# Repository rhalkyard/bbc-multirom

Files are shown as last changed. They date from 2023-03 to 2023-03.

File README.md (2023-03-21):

# MultiROM: A low-cost BBC Master / Electron ROM cartridge

There are plenty of perfectly-good options for building ROM cartridges for the BBC Master and Acorn Electron Plus One. However, I am a stubborn git and enjoy reinventing the wheel for fun, so I decided to come up with my own take on the concept.

Rather than use the 27x and 28x series (E)EPROMS that were used Back In The Day, MultiROM uses a NOR Flash IC, the SST39SF010A. This part is much cheaper and more readily available than EEPROMs, but can still be obtained as a through-hole part for easy DIY assembly. Additionally, it offers more capacity (a whopping one megabit!), which MultiROM uses to store multiple ROM images on one cartridge, selected by DIP switches.

The schematic and PCB layout were produced using [KiCad 7.0](https://www.kicad.org/).

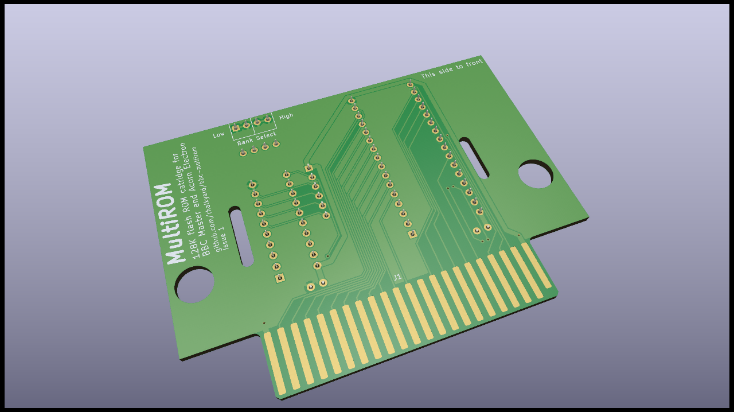
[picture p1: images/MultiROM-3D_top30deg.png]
Three-quarter view of front side of PCB

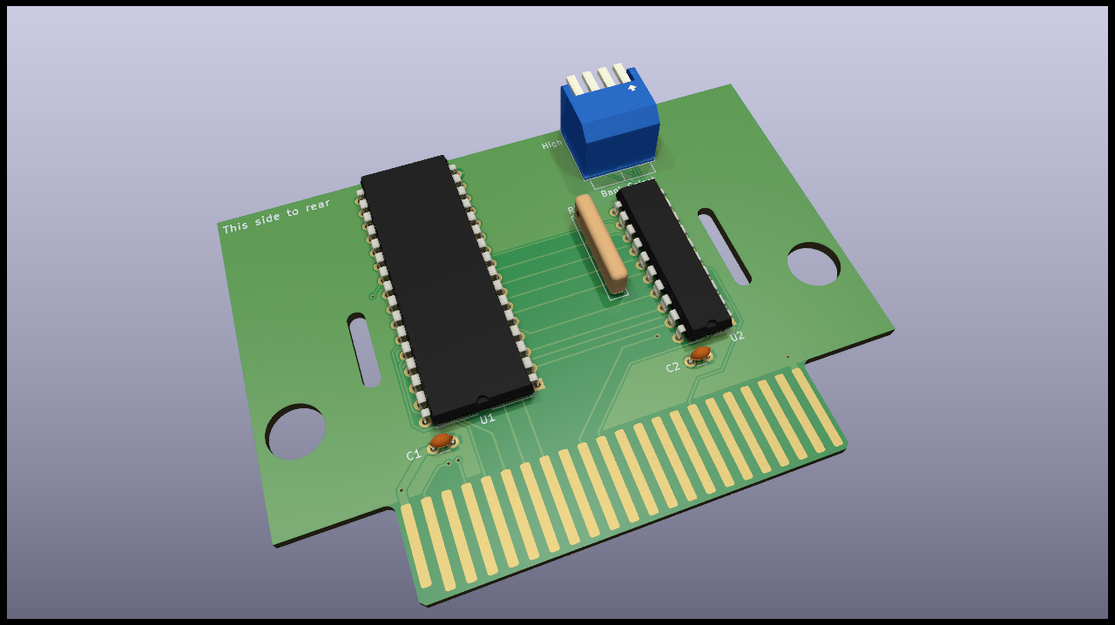
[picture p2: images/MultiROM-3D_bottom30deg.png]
Three-quarter view of rear side of PCB


## How to build MultiROM

### Bill of Materials

Reference   | Part
------------|-------------------------------------------------------------
`C1`, `C2`  | Ceramic capacitor, 0.1μF
`RN1`       | SIP6 resistor network, bussed, 10KΩ
`SW1`       | SPST DIP switch module, 4 switches
`U1`        | SST39SF010 1Mbit flash memory, DIP32 package
`U2`        | GAL16V8 or ATF16V8 programmable logic device, DIP20 package

`RN1` can be omitted if you trust the weak pull-ups built into `U2`. I forgot to order it when building my prototypes, and they seem to work just fine without it.

`SW1` can be omitted if you want the cartridge to function as a basic 2x16k catridge without bank switching.

### PCB

Any PCB fabricator service such as PCBWay, OSHPark or JLCPCB should be able to fabricate the board. Some shops will accept the `.kicad_pcb` file directly, but most will require Gerber and drill files. These can be exported from Kicad using the File -> Fabrication Outputs menu options.

Ideally, the edge connector should have a chamfered board edge and hard gold-plated contacts, to avoid damaging the PCB socket and to ensure a good connection. These are usually extra-cost options that have to be requested when placing the order.

When assembling components onto the PCB, pay attention to which side they are on! Integrated Circuits `U1` and `U2` go on the *back* side of the PCB, with their orientation notches facing towards the edge connector.

This project uses [KiBot](https://github.com/INTI-CMNB/KiBot) to automate output in various formats from KiCad; release archives contain manufacturing files for various popular PCB fabricators.

### GAL

`U2` is a programmable GAL that provides selection and addressing logic compatible with both the Electron and BBC Master.

GALasm source for `U2` can be found in the `pld/` directory, see [the README in that folder](pld/README.md) for instructions on building and programming.

### Cartridge case

The MultiROM PCB is designed to fit in the 'standard' Master/Electron cartridge case produced by Acorn. I do not have a real cartridge to check this against, but I 3D-printed [Paul Boddie's OpenSCAD cartridge](https://hgweb.boddie.org.uk/AcornElectron) and it fits nicely in there.

If the bank-selection DIP switches (`SW1`) are installed, a suitable cutout will need to be made in the case.

Note that there is very little clearance for components inside the case - if the board is to fit inside the case, then the ICs must be soldered directly onto the board rather than socketed.

## How to use MultiROM

### Inserting the cartridge

With the machine powered off, insert MultiROM into either the front or rear cartridge slot. In the rear slot, MultiROM will appear as Sideways ROMs 0 and 1. In the front slot, it will appear as Sideways ROMs 2 and 3.

Keep in mind that the cartridge housing is the only thing preventing a cartridge from being inserted backwards! If using a bare MultiROM board, pay attention to the "This side to front" markings - the correct orientation is with the chips facing *away* from you.

### Switching banks

Each cartridge slot corresponds to two Sideways ROMs - 0 and 1 for the rear cartridge slot, and 2 and 3 for the front. The DIP switch `SW1` on the front of the cartridge allows one of four banks to be selected for each ROM, allowing multiple ROM images to be stored on the cartridge.

The left two switches select the bank for ROM 0 or 2, the right two switches select the bank for ROM 1 or 3.

While switching banks on a running machine is unlikely to cause any permanent harm, it will almost certainly cause the machine to crash the next time a ROM service call is issued. Always reset the machine after switching banks!

### Programming

#### In-System Programming

The [`tools/`](tools/) directory contains software suitable for either a Master or Electron, that can program MultiROM, query Sideways ROM slots, and save Sideways ROMs to tape or disc.

Source is in [BeebASM](https://github.com/stardot/beebasm) format.

#### Using an external programmer

The flash IC can be programmed in an external programmer according to the following memory map.

Address Range   | ROM       |Bank
----------------|-----------|----
00000-03FFF     | Low       | 0
04000-07FFF     | High      | 0
08000-0BFFF     | Low       | 1
0C000-0FFFF     | High      | 1
10000-13FFF     | Low       | 2
14000-17FFF     | High      | 2
18000-1BFFF     | Low       | 3
1C000-1FFFF     | High      | 3

## Technical details

The SST39SF010A is flash memory, and cannot be programmed like a regular EEPROM. Data can only be erased in 4kb sectors, and writes and erase operations are performed using command strings written to 'magic' addresses. Writes can only be made to erased memory. After issuing an erase or write command, the chip must be allowed to complete the operation before continuing.

Completion can be determined by repeatedly reading back the written byte - until the operation is complete, bit 7 will be inverted, and bit 6 will toggle with each subsequent read.

Since the programming process is so convoluted, and regular writes are ignored, a write protection jumper is not provided.

### Flash Commands

Writing, erasing, chip-status and chip-ID functions are accessed by performing a 'magic' sequence of writes, as described in the datasheet, to addresses `5555` and `2AAA`

Because the cartridge slots are mapped into memory starting at address `&8000`, and the low/high ROM select line is used as the 14th address bit, when programming flash on the machine, use the following addresses:

Flash address   | ROM      | BBC Address
----------------|----------|------------
`5555`          | 1 / 3    | `9555`
`2AAA`          | 0 / 2    | `AAAA`

E.g., to write a byte to ROM 0 (i.e. the low ROM in the front cartridge socket), assuming that the sector has been erased:

1. Page in ROM 1
2. Write `&AA` to `&9555`
3. Page in ROM 0
4. Write `&55` to `&AAAA`
5. Page in ROM 1
6. Write `&A0` to `&9555`
7. Page in ROM 0
8. Write a byte to the desired address
9. Repeatedly read back any ROM address until two consecutive reads yield the same data.

This process must be repeated for each byte.

Any spurious reads or writes occurring during this process will cancel the operation or cause undesirable effects - to prevent MOS from interfering it is advisable to disable IRQ interrupts with an `SEI` instruction.

### Example Code

[`tools/flashio.6502`](tools/flashio.6502) contains utility routines for erasing and programming the flash, and safely querying its ID bytes without corrupting Sideways RAM. These were written for use by the tools in that directory, but are heavily commented and designed to be reused.

## TODO

- [ ] Modify [Paul Boddie's OpenSCAD cartridge case](https://hgweb.boddie.org.uk/AcornElectron) to have a cutout for the DIP switches (and maybe cutouts for IC sockets too?).

- [ ] Recruit a volunteer to test cartridge and software functionality on Electron.

## References

- [Phillip Pearson's Electron flash cartridge](https://github.com/google/myelin-acorn-electron-hardware/tree/main/32kb_flash_cartridge) - uses SST39SF010A, but can't be written on a Master, and does not have bank switching.

- [Stardot thread for Retro Hardware ARA III](https://stardot.org.uk/forums/viewtopic.php?t=15629) - writeable cartridge that uses a GAL to support both Electron and Master, but uses expensive 28C256 EEPROM.

- [BooBip.com Sideways Flash Module](http://www.boobip.com/hardware/128kb-flash) - another SST39SF010A-based ROM replacement, designed to plug into internal Sideways ROM sockets.

- [Acorn Application Note 014: Acorn Electron Cartridge Interface Specification](http://chrisacorns.computinghistory.org.uk/docs/Acorn/AN/014.pdf) - Official cartridge interface specs, including differences between Electron and Master.

- [BeebWiki article on Sideways ROM](https://beebwiki.mdfs.net/Paged_ROM) - especially the section on the Electron and its ROM-selection quirks. See also, this [Stardot post](https://stardot.org.uk/forums/viewtopic.php?p=6681#6681) with a technical background on the Electron's ROM selection register.

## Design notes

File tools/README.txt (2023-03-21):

This disc contains tools for managing Sideways ROMs and programming the
MultiROM flash cartridge.

These tools are all suitable to run on either the BBC Master or the Acorn
Electron. They require a PAGE of &1D00, making them suitable for ADFS
Electrons, and file I/O is done only using whole buffers, making them also
suitable for tape systems without motor control.

===============================================================================
LISTROM queries each Sideways ROM slot and outputs a table showing the type of
memory in each slot, and the name and version of the ROM (if present).

Columns are:
    Slot #    Type    Version byte (hex)    Name + Version string

Types are:
    R: ROM    W: Writeable RAM    F: Flash    -: empty    ?: unknown

===============================================================================
SAVEROM saves the contents of a Sideways ROM to tape or disc.

===============================================================================
CARTPRG writes the contents of a file to a Sideways ROM slot on a MultiROM
flash cartridge.

During programming, CARTPRG will print a '*' character for every 512 bytes
programmed, followed by a '#' character for every 512 bytes verified.

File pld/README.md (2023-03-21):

# PLD files for MultiROM

This directory contains GALasm source for the 16V8 PLD used to provide selection and addressing logic.

## Building

Install [GALasm](https://github.com/daveho/GALasm) or [galette](https://github.com/simon-frankau/galette), then run `make` in this directory.

GALasm produces several output files of varying usefulness:

- `.chp` - ASCII-art of chip, with pin names

- `.fus` - tabular description of fuse states

- `.jed` - JEDEC fuse-map file, for programming onto device

- `.pin` - ASCII table of pin names

## Programming

Note that the GAL16V8 device specified in the source is out of production. The [Atmel ATF16V8B](https://www.microchip.com/en-us/product/ATF16V8B) is a compatible in-production equivalent.

The ubiquitous [XGecu](http://www.autoelectric.cn/en/TL866_main.html) (a.k.a. TL866) USB programmers are probably the cheapest and easiest way to program small PLDs (and numerous other chips).

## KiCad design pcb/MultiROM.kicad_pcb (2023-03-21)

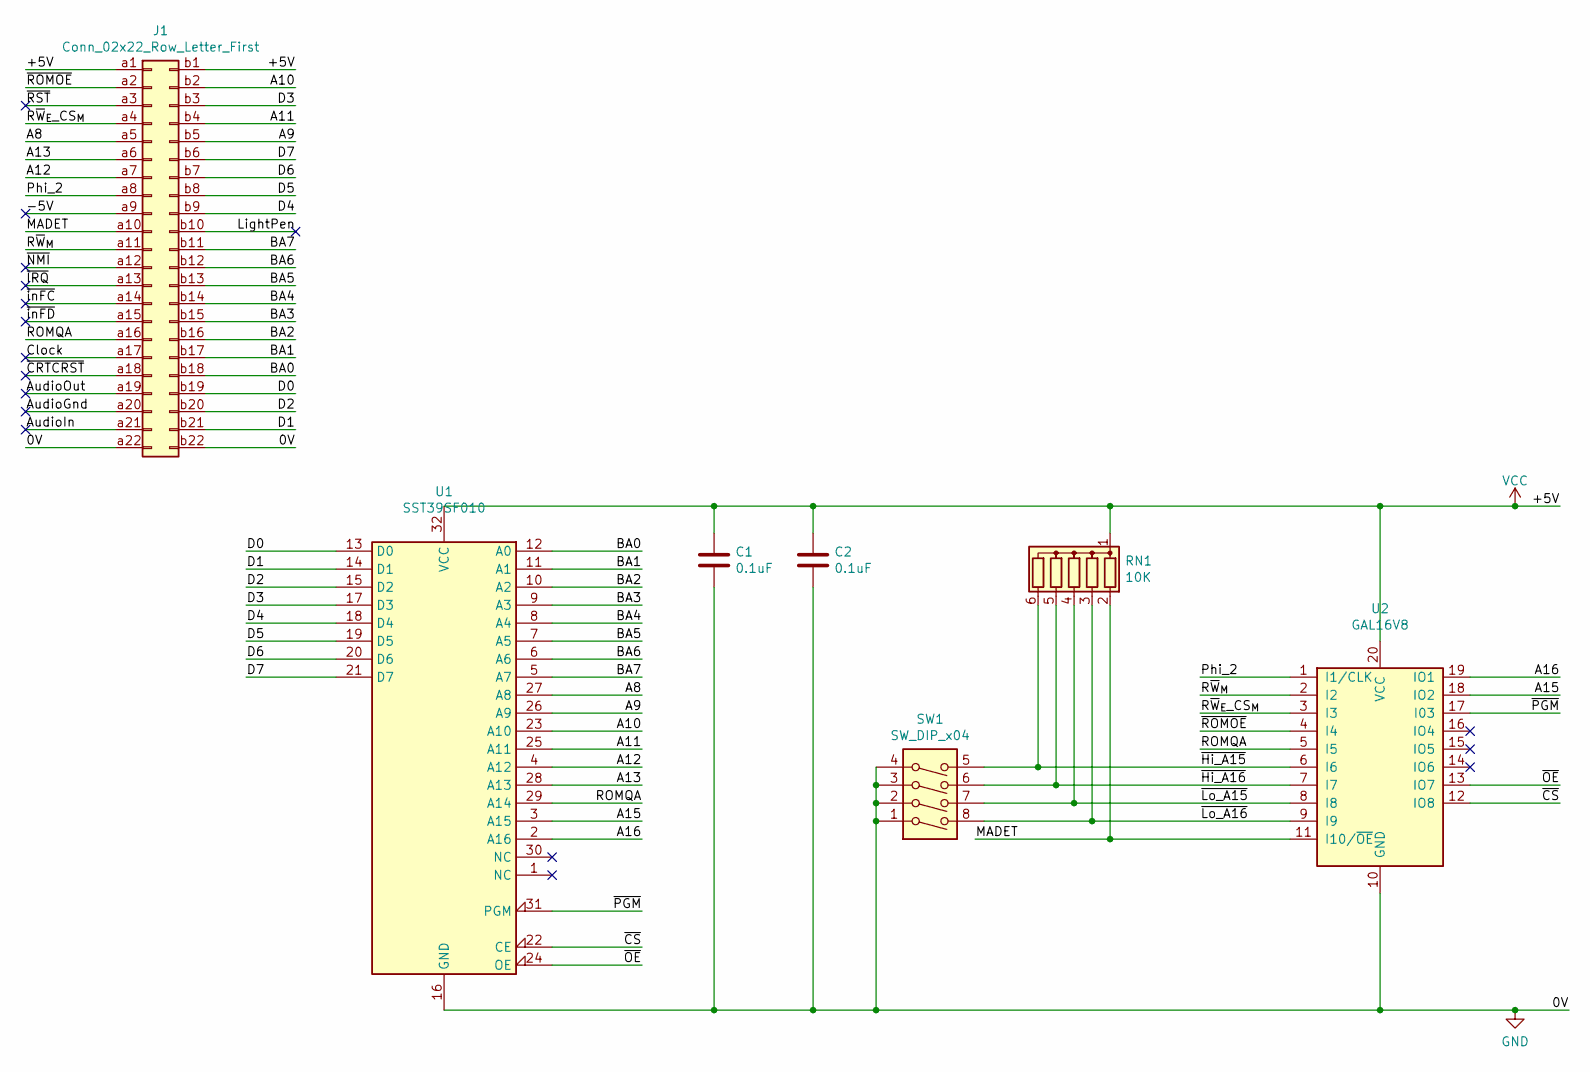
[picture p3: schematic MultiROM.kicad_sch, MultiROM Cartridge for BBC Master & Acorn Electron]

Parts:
C1, C2: 0.1uF; C_Disc_D3.0mm_W1.6mm_P2.50mm
J1: Conn_02x22_Row_Letter_First; bbc-master-acorn-electron-cartridge
RN1: 10K; R_Array_SIP6
SW1: SW_DIP_x04; SW_DIP_SPSTx04_Piano_10.8x11.72mm_W7.62mm_P2.54mm
U1: SST39SF010; DIP-32_W15.24mm
U2: GAL16V8; DIP-20_W7.62mm

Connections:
/-5V: J1.a9
/A8: J1.a5, U1.27 (A8)
/A9: J1.b5, U1.26 (A9)
/A10: J1.b2, U1.23 (A10)
/A11: J1.b4, U1.25 (A11)
/A12: J1.a7, U1.4 (A12)
/A13: J1.a6, U1.28 (A13)
/A15: U1.3 (A15), U2.18 (IO2)
/A16: U1.2 (A16), U2.19 (IO1)
/AudioGnd: J1.a20
/AudioIn: J1.a21
/AudioOut: J1.a19
/BA0: J1.b18, U1.12 (A0)
/BA1: J1.b17, U1.11 (A1)
/BA2: J1.b16, U1.10 (A2)
/BA3: J1.b15, U1.9 (A3)
/BA4: J1.b14, U1.8 (A4)
/BA5: J1.b13, U1.7 (A5)
/BA6: J1.b12, U1.6 (A6)
/BA7: J1.b11, U1.5 (A7)
/Clock: J1.a17
/D0: J1.b19, U1.13 (D0)
/D1: J1.b21, U1.14 (D1)
/D2: J1.b20, U1.15 (D2)
/D3: J1.b3, U1.17 (D3)
/D4: J1.b9, U1.18 (D4)
/D5: J1.b8, U1.19 (D5)
/D6: J1.b7, U1.20 (D6)
/D7: J1.b6, U1.21 (D7)
/LightPen: J1.b10
/MADET: J1.a10, RN1.2 (R1), U2.11 (I10/~OE)
/Phi_2: J1.a8, U2.1 (I1/CLK)
/ROMQA: J1.a16, U1.29 (A14), U2.5 (I5)
/R~W_{E}_CS_{M}: J1.a4, U2.3 (I3)
/R~W_{M}: J1.a11, U2.2 (I2)
/~CRTCRST: J1.a18
/~CS: U1.22 (CE), U2.12 (IO8)
/~Hi_A15: RN1.6 (R5), SW1.5, U2.6 (I6)
/~Hi_A16: RN1.5 (R4), SW1.6, U2.7 (I7)
/~IRQ: J1.a13
/~Lo_A15: RN1.4 (R3), SW1.7, U2.8 (I8)
/~Lo_A16: RN1.3 (R2), SW1.8, U2.9 (I9)
/~NMI: J1.a12
/~OE: U1.24 (OE), U2.13 (IO7)
/~PGM: U1.31 (PGM), U2.17 (I03)
/~ROMOE: J1.a2, U2.4 (I4)
/~RST: J1.a3
/~inFC: J1.a14
/~inFD: J1.a15
GND: C1.2, C2.2, J1.a22, J1.b22, SW1.1, SW1.2, SW1.3, SW1.4, U1.16 (GND), U2.10 (GND)
VCC: C1.1, C2.1, J1.a1, J1.b1, RN1.1 (common), U1.32 (VCC), U2.20 (VCC)

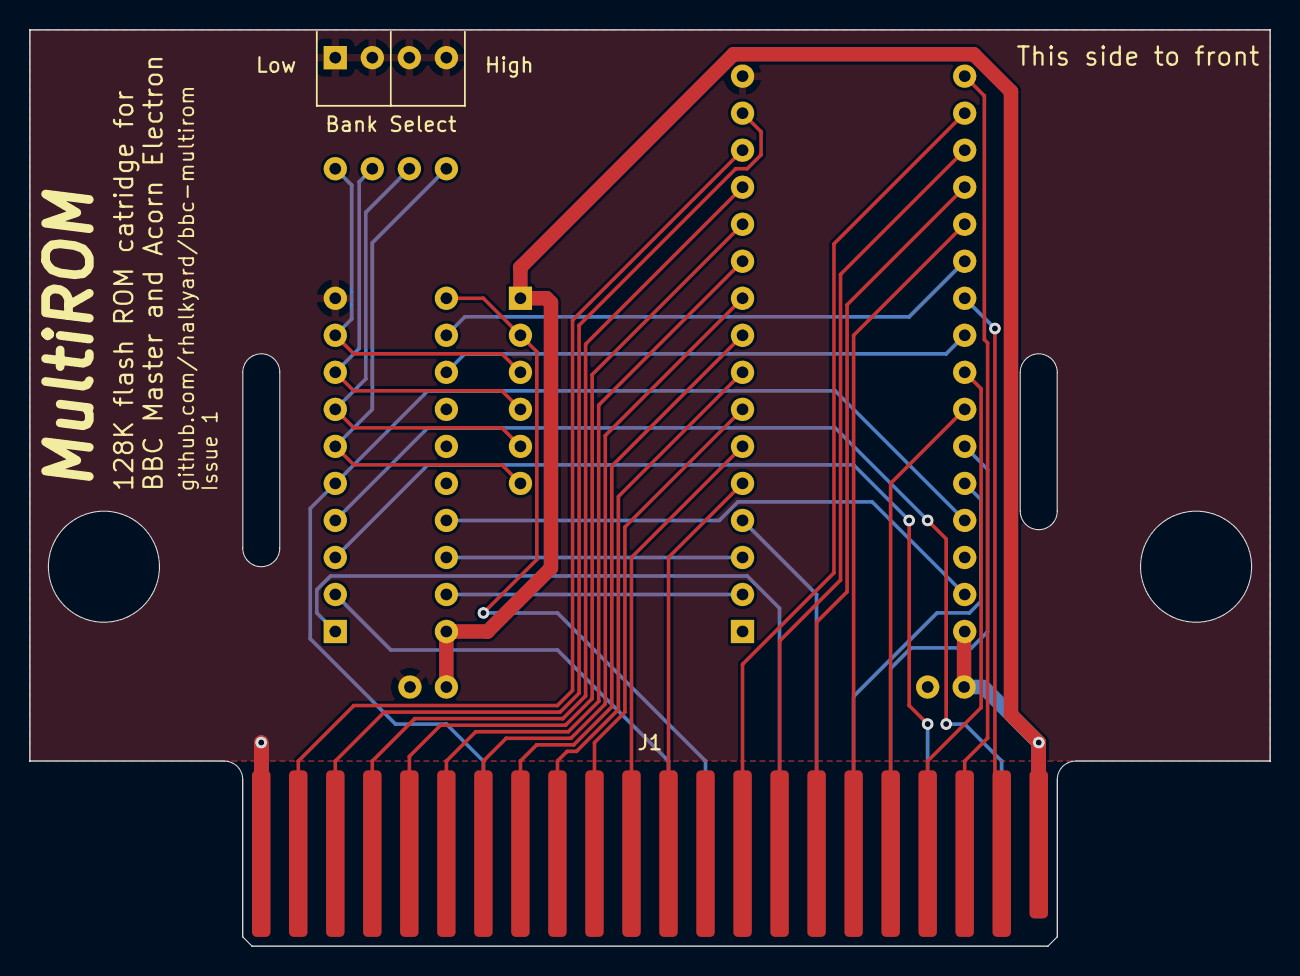
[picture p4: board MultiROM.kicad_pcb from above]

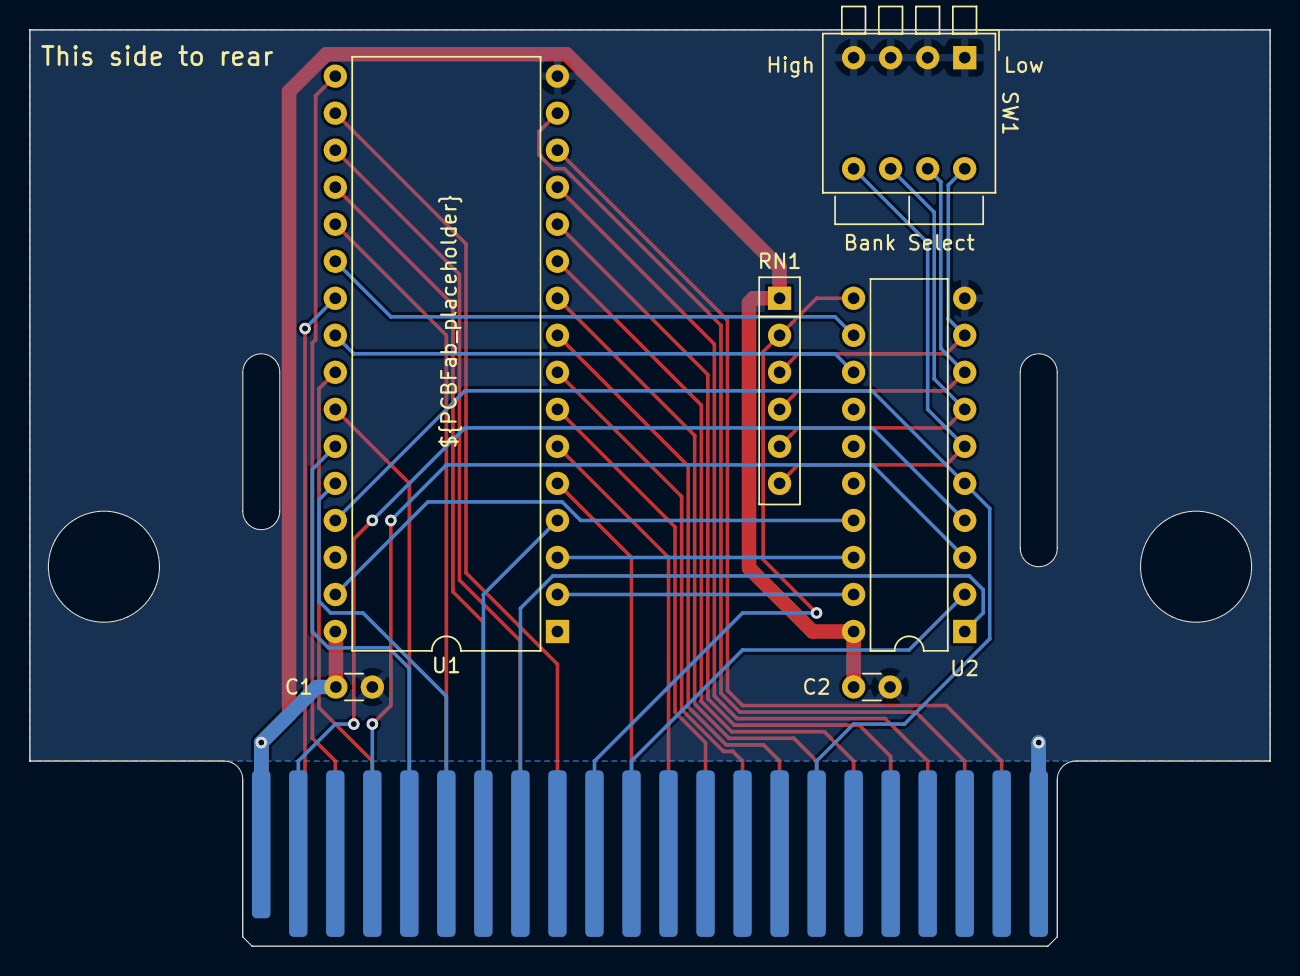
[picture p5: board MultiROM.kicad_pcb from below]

Board: 2 copper layers, 85.1 x 62.9 mm, 7 parts (6 on the bottom side), 39 nets.

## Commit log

2023-03-21 Prototype #1 as-built
    [MultiROM.kicad_pcb, MultiROM.kicad_sch]
2023-03-21 PCB revisions post proto#1
    [MultiROM.kicad_pcb, MultiROM.kicad_sch]
2023-03-21 Move PCB into separate directory
    [MultiROM.kicad_pcb, MultiROM.kicad_sch]
2023-03-21 add tube check
2023-03-21 Harmonise PLD pin names between CUPL and GALasm
2023-03-21 PCB+netlist tidyup
    [MultiROM.kicad_pcb, MultiROM.kicad_sch]
2023-03-21 Placeholder text for fab info
    [MultiROM.kicad_pcb]
2023-03-21 Rename cartridge footprint+library to avoid spaces
    [MultiROM.kicad_pcb, MultiROM.kicad_sch]
2023-03-21 Build system
    [MultiROM.kicad_pcb, MultiROM.kicad_sch]
2023-03-21 keep version string empty until populated
    [MultiROM.kicad_pcb]
2023-03-21 Correct order of ROM paging switches
2023-03-21 Give up on PCB text variables for now
    [MultiROM.kicad_pcb]
2023-03-21 Redo PCB variables
    [MultiROM.kicad_pcb, MultiROM.kicad_sch]
2023-03-21 Use edge-style DIP switch
    [MultiROM.kicad_pcb, MultiROM.kicad_sch]
2023-03-21 Exclude edge connector from BOM
    [MultiROM.kicad_sch]
2023-03-21 Move front switch labels to sides
    [MultiROM.kicad_pcb]
2023-03-21 Issue 1
    [MultiROM.kicad_pcb]
